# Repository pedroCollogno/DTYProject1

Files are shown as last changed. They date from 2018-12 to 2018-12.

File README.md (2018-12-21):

# Mobil'IOT

## Intro globale

Mobil'IOT est un projet visant à développer un objet connecté à l'application Mobil'IT V2, qui permettrait aux inspecteurs de réaliser facilement différentes mesures sur le terrain ;

* De *distances* (P0)
* De luminosité (P1)
* De niveau sonore (P1)

**Disclaimer:**

La documention de l'objet ne remplace pas celle de l'appli, mais en est plutôt un complément.

### Qui l'a développée ?

Mobili'IOT est un projet qui a démarré le 10 septembre 2018 et qui regroupe quatre étudiants de CentraleSupélec dans le cadre de la Digital Tech Year, en lien avec le projet Mobil'IT V2, qui vise une refonte de l'appli, avec 4 autres étudiants.

Projet Mobil'IOT :

* BELIGON Mathieu [mathieu.beligon@student.ecp.fr](mailto:mathieu.beligon@student.ecp.fr)
* COLLIGNON Pierre [pierre.collignon@supelec.fr](mailto:pierre.collignon@supelec.fr)
* CORDELLE Antoine [antoine.cordelle@supelec.fr](mailto:antoine.cordelle@supelec.fr)
* FEDRIGO Mathieu [mathieu.fedrigo@supelec.fr](mailto:mathieu.fedrigo@supelec.fr)

Projet Mobil'IT V2 :

* GOUTALLIER Arthur [arthur.goutallier@student.ecp.fr](mailto:arthur.goutallier@student.ecp.fr)
* KADIRI Hamza  [hamza.kadiri@student.ecp.fr](mailto:hamza.kadiri@student.ecp.fr)
* LUCAS Hadrien [hadrien.lucas@student.ecp.fr](mailto:hadrien.lucas@student.ecp.fr)
* VIOSSAT Paul [paul.viossat@student.ecp.fr](mailto:paul.viossat@student.ecp.fr)

## Mise en place de l'application

Voir le REAMDE de l'application, qui reprend l'installation en local de l'app et de la bdd associée.

------------------------------------------------------------------------------------------

# Le prototype

## Matériel nécessaire

Voici le matériel nécessaire pour prototyper l'objet:

* [Un capteur de distance TFMini](https://www.amazon.fr/UNIKEL-D%C3%A9tecteur-Ranging-Unidirectionnel-Raspberry/dp/B07C7CXMHR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)
* [Un capteur de volume sonore KY-037](https://www.amazon.fr/Carte-AZDelivery-pour-Arduino-microphone/dp/B07CN3D77S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)
* [Un capteur de luminosité BH1750](https://www.amazon.fr/Capteur-Luminosit%C3%A9-Couteau-temt6000-Analogique-prototypage/dp/B01N5KZCQJ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)
* [Un module bluetooth HM-10](https://www.amazon.fr/DSD-TECH-Bluetooth-iBeacon-Arduino/dp/B06WGZB2N4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)
* [Un module 4*7 segments](https://www.amazon.fr/AZDelivery-Digital-Display-Arduino-Raspberry/dp/B078S8SGW2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)
* 4 boutons poussoir
* 3 leds
* [Un buzzer](https://www.amazon.fr/Buzzer-Actif-continu-Arduino-Domotique/dp/B00GX6YCBI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)
* Une carte Arduino Nano
* Des piles 9V
* [Des adaptateurs pour les piles](https://www.amazon.fr/KEESIN-batterie-bouton-Prise-Support/dp/B06Y41ZRVJ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)

## Cablage

Voir le dossier PCB, et s'assurer que les pins sur le code (fichier ino) sont bien configurés.

## Code

Il faut adapter à votre prototype:

* Les pins (fichier pins.hpp) si besoin ;
* Le nombre de capteurs (fichiers MobilIOT.ino), et leur type.

Transférer le code MobilIOT sur la nano, et enjoy !

## Documentation

# Les composants

LUX (nouveau capteur) : [github.com/claws/BH1750](github.com/claws/BH1750)

DIST : [github.com/TFmini/TFmini-Arduino](github.com/TFmini/TFmini-Arduino)

TEMPERATURE : [https://www.carnetdumaker.net/articles/mesurer-une-temperature-avec-un-capteur-1-wire-ds18b20-et-une-carte-arduino-genuino/](https://www.carnetdumaker.net/articles/mesurer-une-temperature-avec-un-capteur-1-wire-ds18b20-et-une-carte-arduino-genuino/)

## Le code

### Librairies utilisées

 - DallasTemperature (capteur de température)
 - TFMini (lidar)
 - TM1637Display (7segments)
 - https://github.com/tedyapo/arduino-VEML7700 (luxmeter)

### Organisation

Le fichier main doit renseigner les différents Capteurs, qui permettent d'accéder aux grandeurs mesurées, à l'unité à afficher sur le 7 segments, ainsi qu'aux pins de la led et du bouton correspondant au capteur.

Pour rajouter un nouveau capteur, il suffit donc d'hériter de la classe Capteur, de redéfinir les méthodes nécessaires, et d'instancier ce capteur dans la liste du fichier main, en renseignant ses pins.

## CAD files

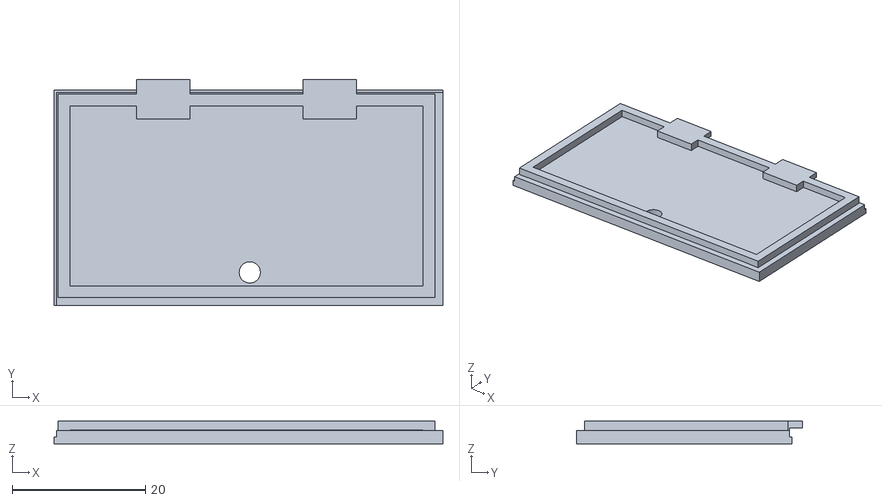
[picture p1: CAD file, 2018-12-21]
3D/Couvercle_de_la_batterie.stl
58.4 x 34.0 x 3.40

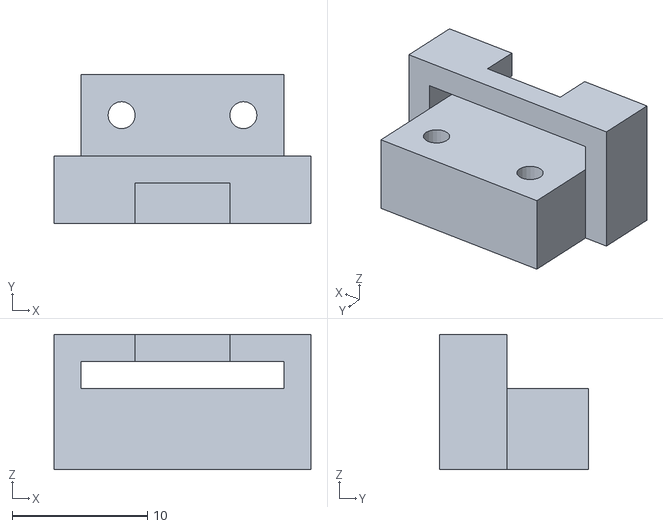
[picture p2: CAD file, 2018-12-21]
3D/Extension_pour_le_capteur_lux.stl
19.0 x 11.0 x 10.0

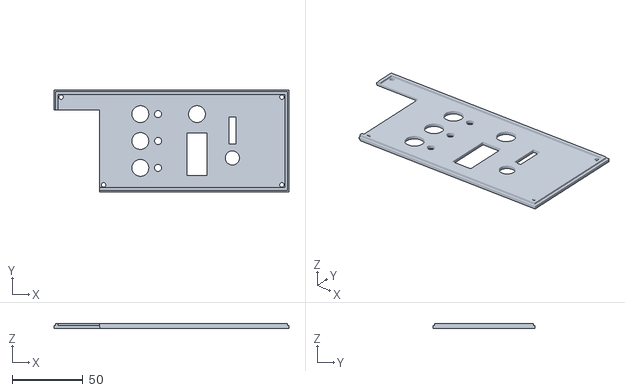
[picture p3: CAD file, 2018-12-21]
3D/Couvercle.stl
166.0 x 72.0 x 3.40

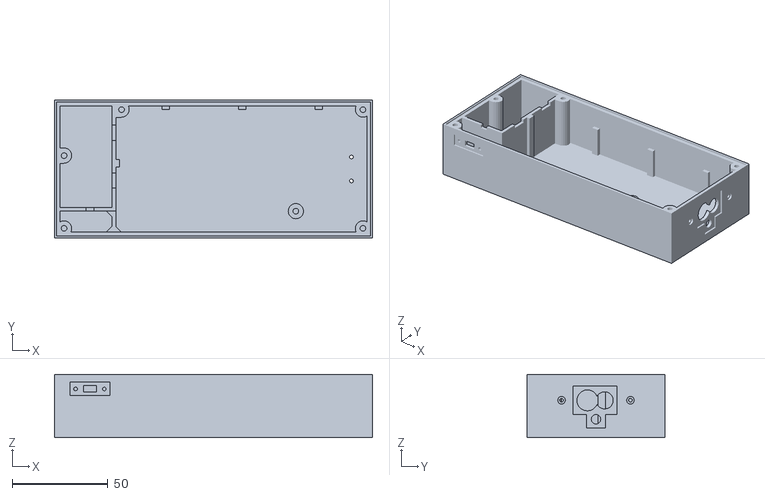
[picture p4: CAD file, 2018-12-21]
3D/Boite.stl
166.0 x 72.0 x 33.0

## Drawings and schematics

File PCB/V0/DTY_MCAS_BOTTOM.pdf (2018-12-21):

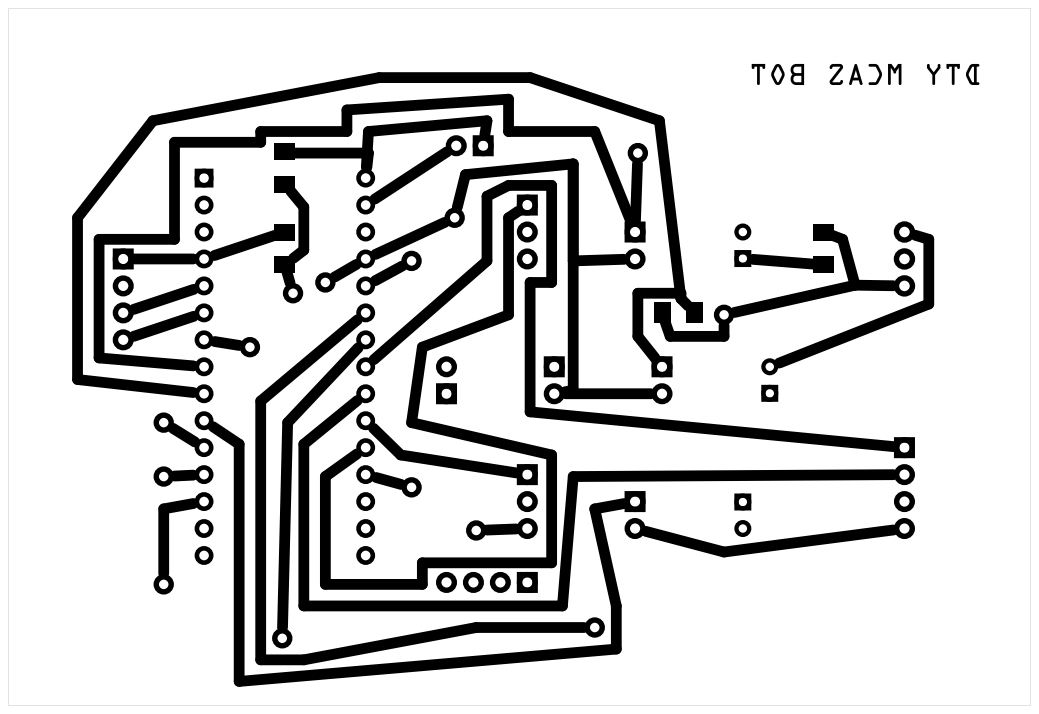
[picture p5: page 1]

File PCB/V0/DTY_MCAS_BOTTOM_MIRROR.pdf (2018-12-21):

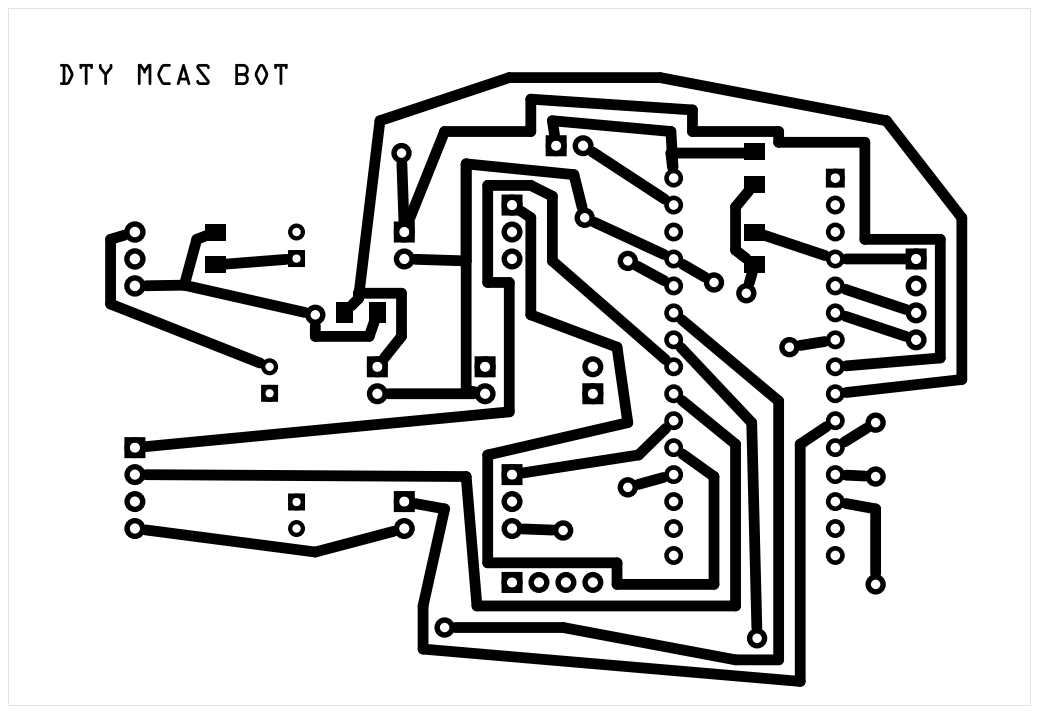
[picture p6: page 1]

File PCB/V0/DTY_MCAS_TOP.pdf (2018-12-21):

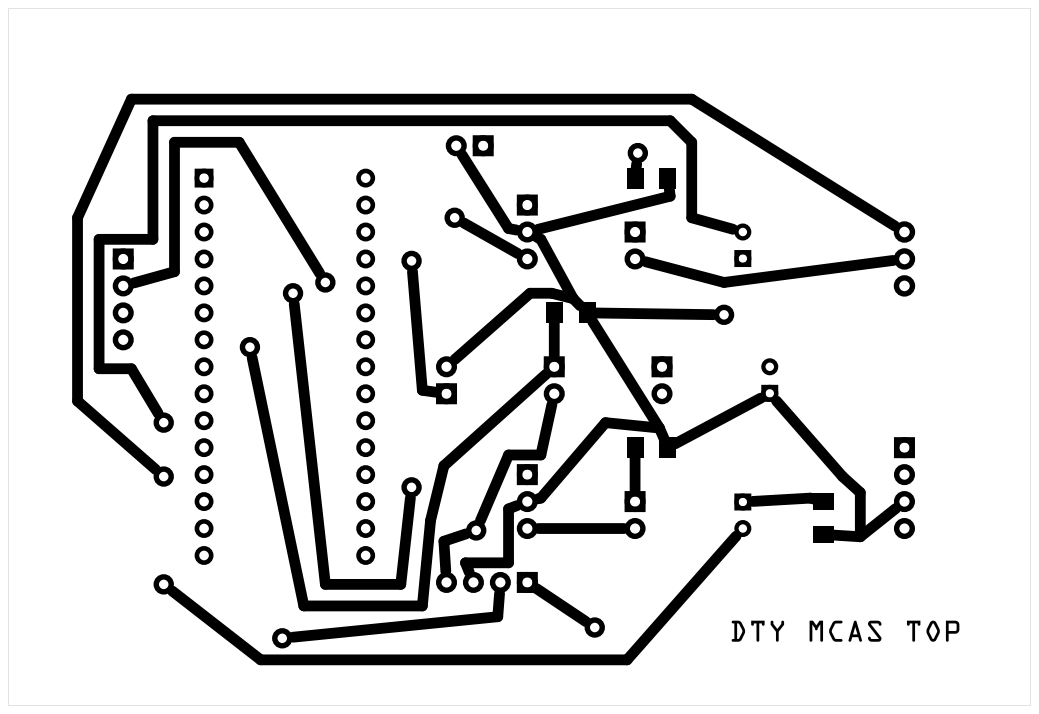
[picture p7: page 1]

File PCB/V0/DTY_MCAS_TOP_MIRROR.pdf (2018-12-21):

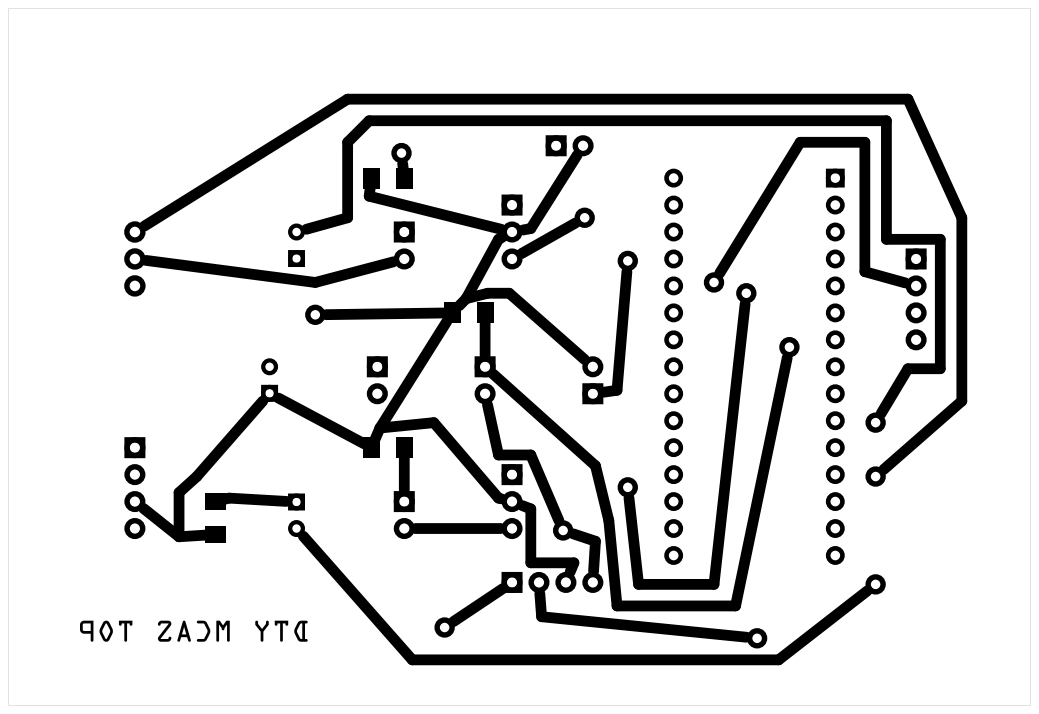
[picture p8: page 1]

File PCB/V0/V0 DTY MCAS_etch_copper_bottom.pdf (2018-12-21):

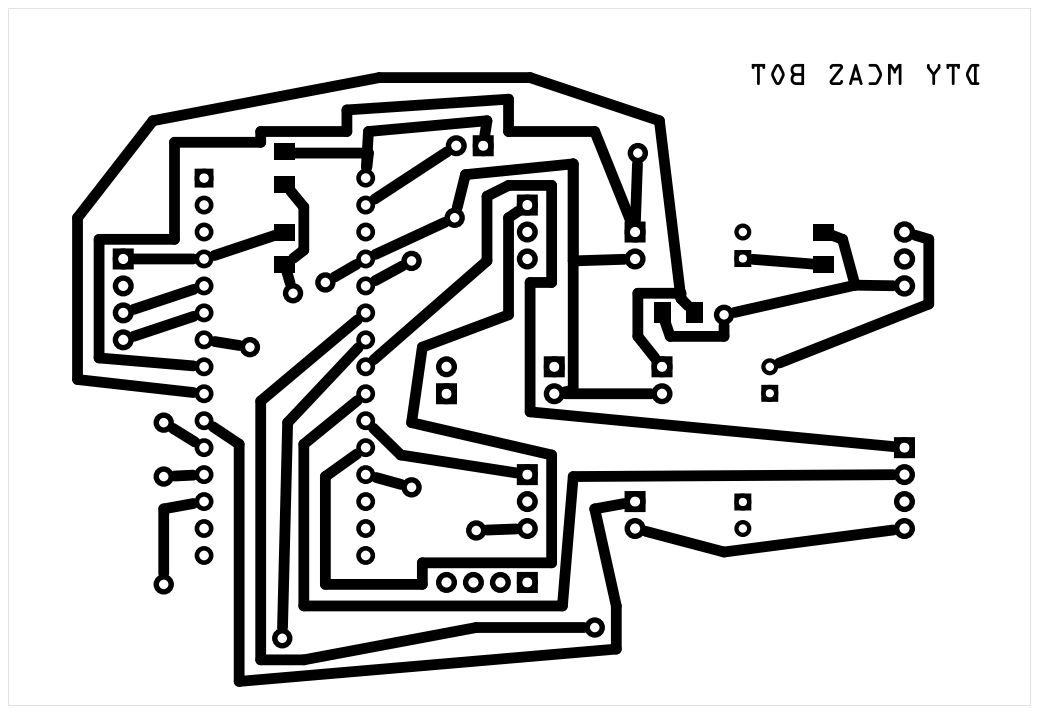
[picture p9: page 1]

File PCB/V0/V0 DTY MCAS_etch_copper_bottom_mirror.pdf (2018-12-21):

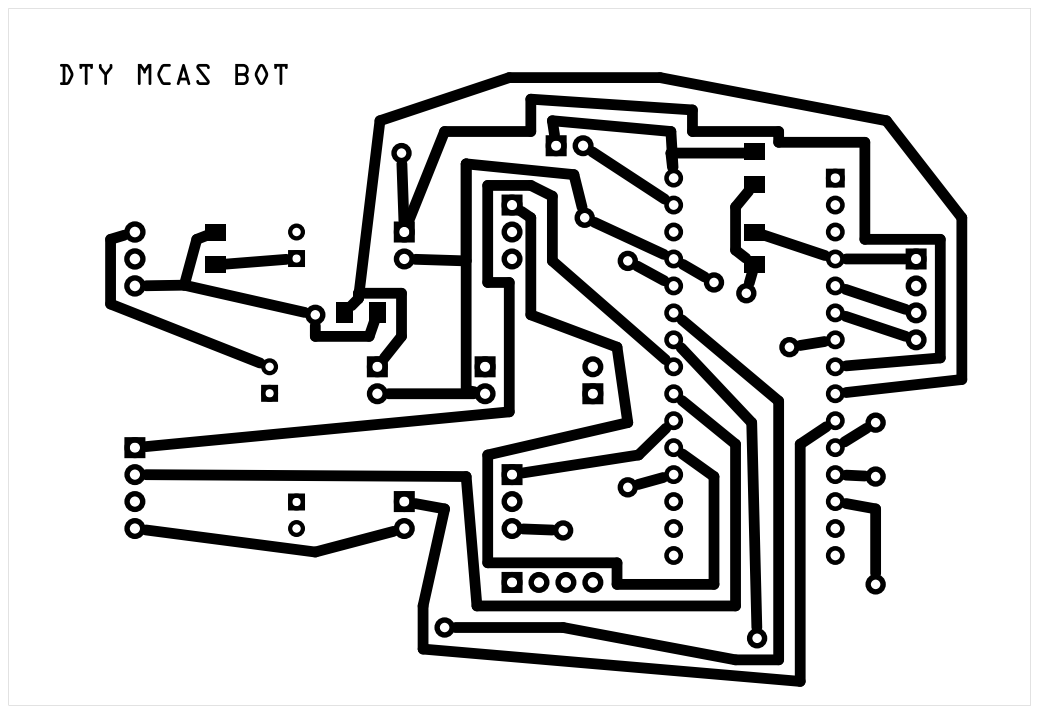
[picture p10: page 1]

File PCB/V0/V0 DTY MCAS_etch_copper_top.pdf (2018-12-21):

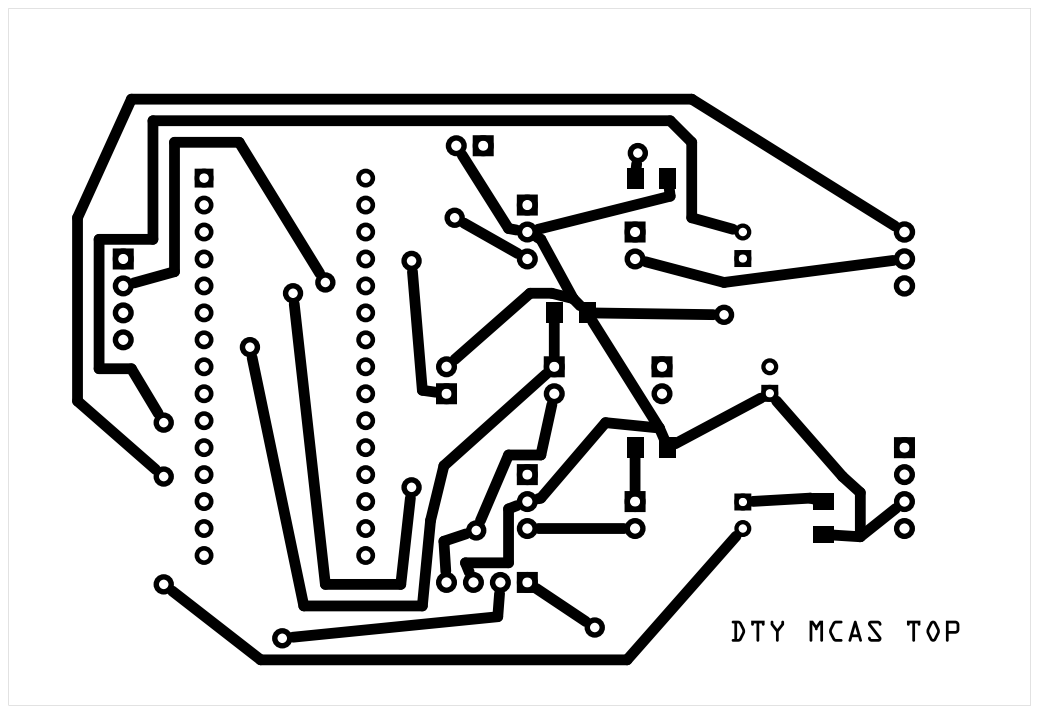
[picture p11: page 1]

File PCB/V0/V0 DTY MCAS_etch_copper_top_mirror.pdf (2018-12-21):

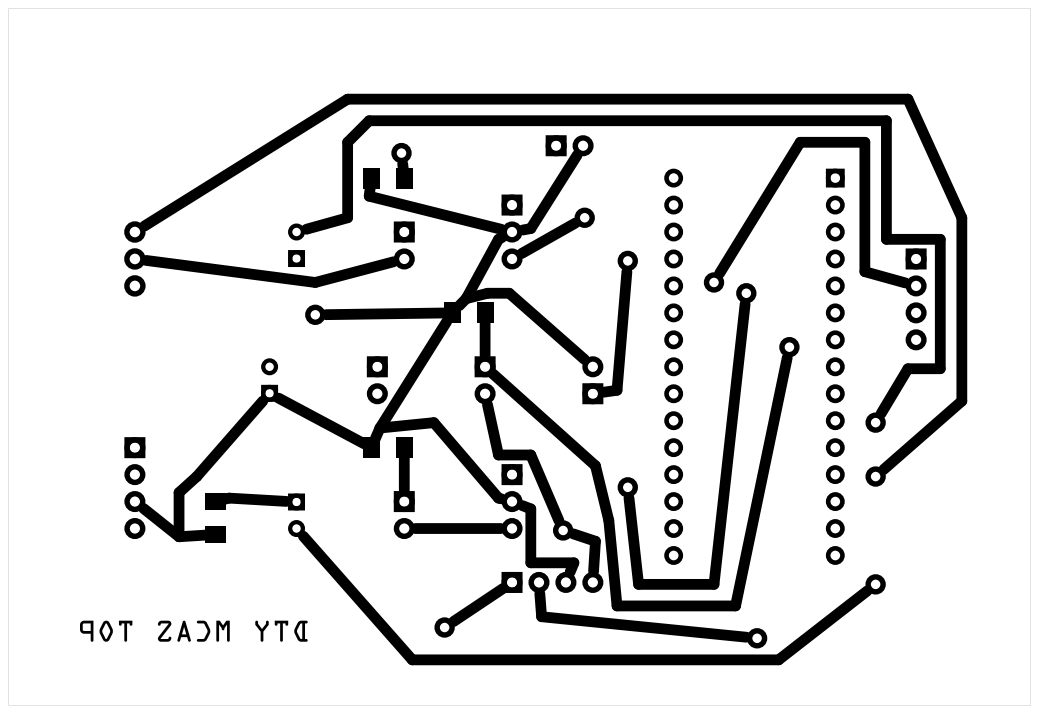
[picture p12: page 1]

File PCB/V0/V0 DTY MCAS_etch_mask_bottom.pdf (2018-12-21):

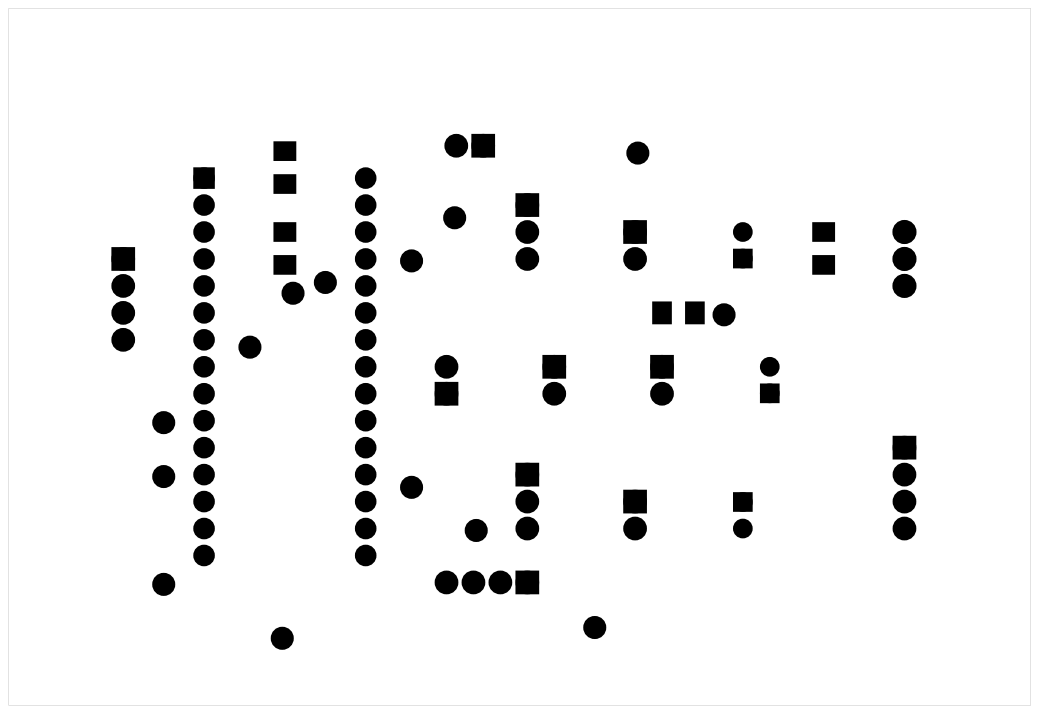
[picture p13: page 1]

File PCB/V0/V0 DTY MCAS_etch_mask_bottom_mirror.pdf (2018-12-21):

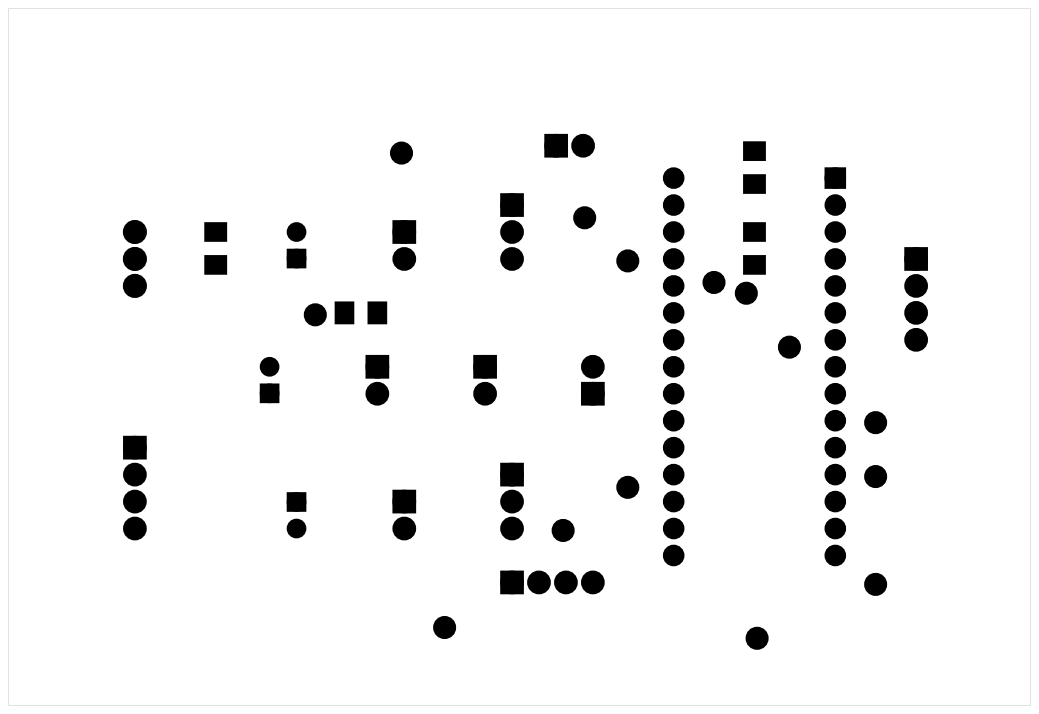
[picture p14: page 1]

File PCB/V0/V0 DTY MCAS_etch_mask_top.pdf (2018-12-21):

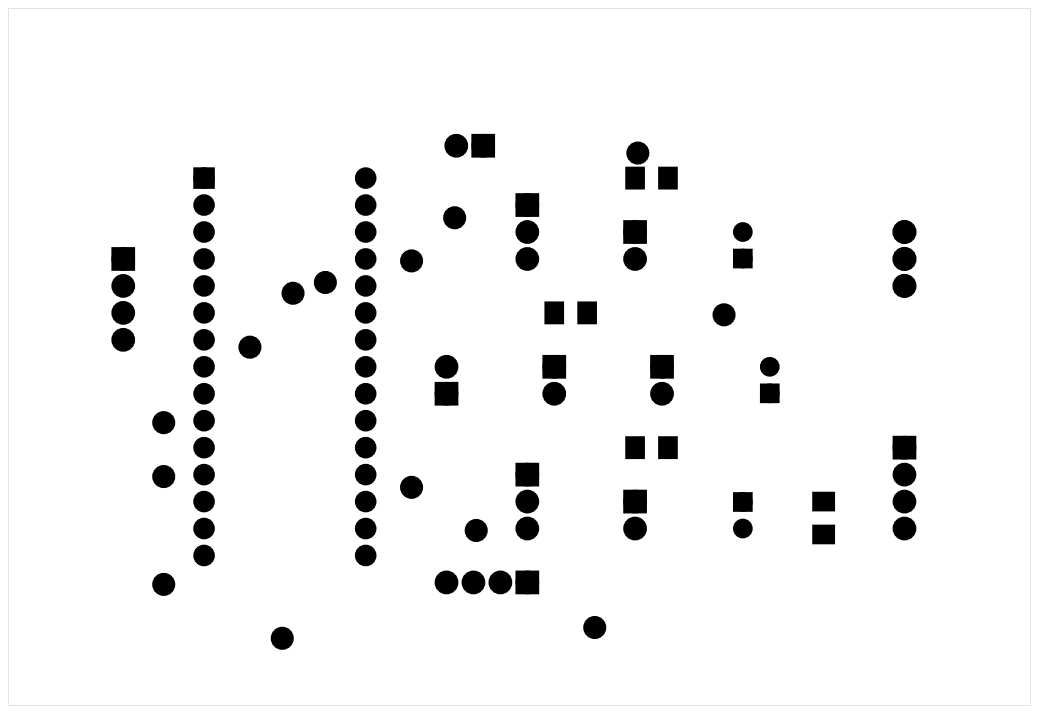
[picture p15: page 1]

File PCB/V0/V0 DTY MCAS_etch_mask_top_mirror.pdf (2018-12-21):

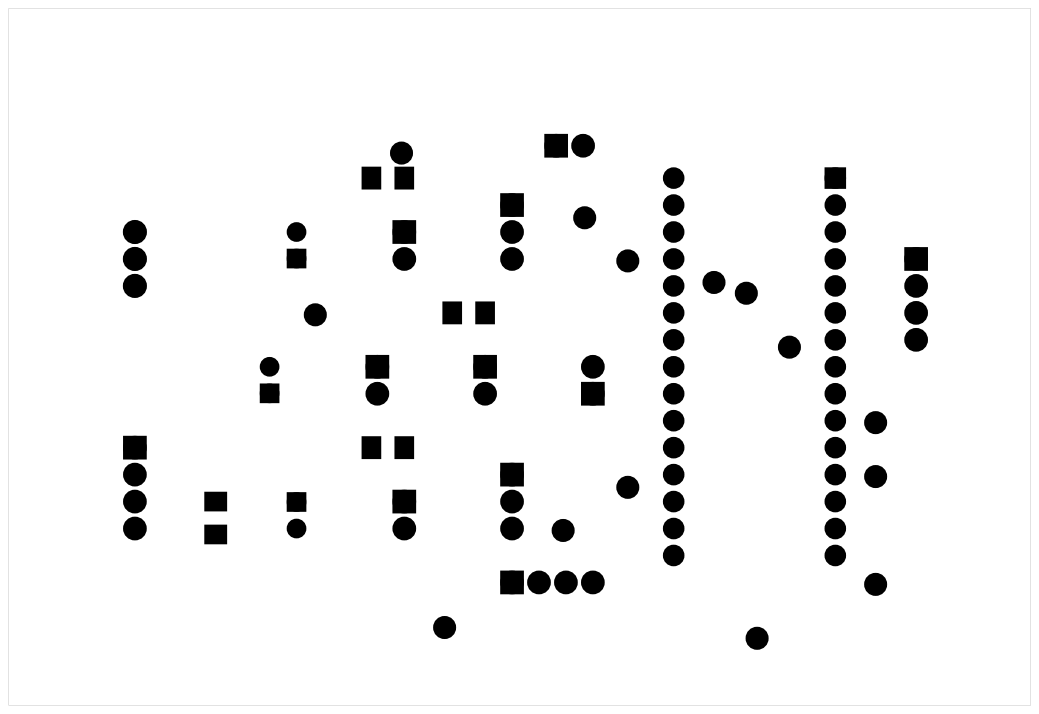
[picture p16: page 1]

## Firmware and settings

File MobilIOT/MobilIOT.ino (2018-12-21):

#include <Arduino.h>
#include <TM1637Display.h>
#include <EEPROM.h>

#include "pitches.h"

#include "Capteur.hpp"
#include "CapteurLux.hpp"
#include "CapteurDist.hpp"
#include "CapteurSon.hpp"
#include "CapteurTemp.hpp"

#include "Bluetooth.hpp"
#include "Batterie.hpp"

#include "pins_3d.hpp"

#define NB_MAX_VALUES 300

#define DELAY_AFFICHAGE 50
#define DELAY_REACTION 10

#define BATTERIE_COUNT_UPDATE 100

unsigned int values[NB_MAX_VALUES];

const int NB_CAPTEURS = 3;
Capteur* capteurs[NB_CAPTEURS] = {
  // new CapteurTemp(values, NB_MAX_VALUES, PIN_SWITCH_TO_LUX, PIN_LED_LUX, A4), //TEMP
  new CapteurDist(values, NB_MAX_VALUES, PIN_SWITCH_TO_DIST, PIN_LED_DIST, PIN_RX_TFMINI, PIN_TX_TFMINI, OFFSET_DISTANCE), //DIST
  new CapteurLux(values, NB_MAX_VALUES, PIN_SWITCH_TO_LUX, PIN_LED_LUX), //LUX
  new CapteurSon(values, NB_MAX_VALUES, PIN_SWITCH_TO_SONO, PIN_LED_SONO, PIN_SONO)}; //SONO


Bluetooth bluetooth(PIN_RX_BLUETOOTH, PIN_TX_BLUETOOTH);

Batterie * battery(new Pile9V_6LR61(PIN_BATTERIE));

/* Affichage */
TM1637Display display(PIN_7SEG_CLK, PIN_7SEG_DIO);

const uint8_t no_values[] = {
  SEG_G,
  SEG_G,
  SEG_G,
};
const uint8_t empty[] = {0};

long prev_affichage(0);

/* L'état de l'objet */
struct EtatMobilIOT {
  bool measuring;
  Capteur* capteur;
  float value;
};

EtatMobilIOT etat = {
  false,
  capteurs[0],
  0
};

VEML7700 als;

void setup()
{

  for(int i = 0; i < NB_CAPTEURS; i++){
    pinMode(capteurs[i]->getPinLed(), OUTPUT);
    pinMode(capteurs[i]->getPinSwitch(), INPUT);
  }
  
  Serial.begin(9600);
  Serial.println("coucou");
  
  als.begin();

  bluetooth.init();

  display.setBrightness(0x0f);

  pinMode(PIN_TAKE_MEASUREMENT, INPUT);
  pinMode(PIN_LASER, OUTPUT);

  pinMode(PIN_BATTERIE, INPUT);
  pinMode(PIN_HP, OUTPUT);
}

int count(0);
void loop()
{
  ///=====================
  // Test if we are measuring

  long measure_start(millis());

  if(digitalRead(PIN_TAKE_MEASUREMENT) == HIGH){
    //Alert the captor if needed
    if(etat.measuring == false)
      etat.capteur->init();
    etat.measuring = true;
  }
  else if(etat.measuring){
    //send the datas
    int nb_values = etat.capteur->getNbValues();

    bluetooth.send_values(values, nb_values, etat.capteur->getSendableUnity());

    tone(PIN_HP, NOTE_E6, 1000/16);
    delay(1000/16*1.3);
    noTone(PIN_HP);
    tone(PIN_HP, NOTE_G6, 1000/16);
    delay(1000/16*1.3);
    noTone(PIN_HP);
    tone(PIN_HP, NOTE_C7, 1000/4);
    delay(1000/4*1.3);
    noTone(PIN_HP);

    etat.measuring = false;
  }

  ///=====================
  // Change mode
  for(int i = 0; i<NB_CAPTEURS; i++){
    if(digitalRead(capteurs[i]->getPinSwitch()) == HIGH){
      etat.capteur = capteurs[i];
      etat.value = 0;
    }
  }

  for(int i = 0; i<NB_CAPTEURS; i++)
    digitalWrite(capteurs[i]->getPinLed(), etat.capteur == capteurs[i] ? HIGH : LOW);

  digitalWrite(PIN_LASER, etat.measuring && etat.capteur->getPinLed() == PIN_LED_DIST ? HIGH : LOW);

  ///=====================
  // Update the value if needed
  if(etat.measuring)
    etat.value = etat.capteur->getValue() / 10;

  ///=====================
  // Display

  //Display the unit
  display.setSegments(etat.capteur->getUnity(), 1, 3);

  //Display the value
  if(millis() - prev_affichage > DELAY_AFFICHAGE){
    int toDisplay = min(999, max(0, etat.value));
    for(int i = 0; i<3; i++){
      if(toDisplay)
        display.showNumberDec(toDisplay%10, true, 1, 2-i);
      else if(etat.value)
        display.setSegments(empty, 1, 2-i);
      toDisplay /= 10;
    }
    prev_affichage = millis();
  }

  if(etat.value == 0)
    display.setSegments(no_values, 3, 0);

  if(!count)
    bluetooth.send_values(battery->getPercentage(), 1, "battery");
  count = (count+1) % BATTERIE_COUNT_UPDATE;

  ///=====================
  // Wait some time
  if(etat.measuring)
    delay(max(1, DELAY_REACTION - ((long)millis() - measure_start)));
}

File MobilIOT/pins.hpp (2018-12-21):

// Module connection pins (Digital Pins)
#define PIN_7SEG_CLK 4
#define PIN_7SEG_DIO 5

#define PIN_TAKE_MEASUREMENT 8

#define PIN_SWITCH_TO_SONO 6
#define PIN_SWITCH_TO_DIST 9
#define PIN_SWITCH_TO_LUX 11

#define PIN_LED_SONO 7
#define PIN_LED_DIST 13
#define PIN_LASER 10
#define PIN_LED_LUX 12

#define PIN_LUX A4

#define PIN_SONO A5

#define PIN_RX_TFMINI A0 //VERT
#define PIN_TX_TFMINI A1

#define PIN_HP A3

#define PIN_BATTERIE A2

#define PIN_RX_BLUETOOTH 3
#define PIN_TX_BLUETOOTH 2

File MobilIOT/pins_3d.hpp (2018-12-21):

// Module connection pins (Digital Pins)
#define PIN_7SEG_CLK 4
#define PIN_7SEG_DIO 5

#define PIN_TAKE_MEASUREMENT 7

#define PIN_SWITCH_TO_SONO 13
#define PIN_SWITCH_TO_DIST 11
#define PIN_SWITCH_TO_LUX 9

#define PIN_LED_SONO 10
#define PIN_LED_DIST 12
#define PIN_LASER 6
#define PIN_LED_LUX 8

#define PIN_SONO A7

#define PIN_RX_TFMINI A0 //VERT
#define PIN_TX_TFMINI A1

#define PIN_HP A2

#define PIN_BATTERIE A3

#define PIN_RX_BLUETOOTH 3
#define PIN_TX_BLUETOOTH 2

#define OFFSET_DISTANCE 174
